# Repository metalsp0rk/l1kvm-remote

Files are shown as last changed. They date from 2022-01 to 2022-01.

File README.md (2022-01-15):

# Level1Techs KVM Remote

USB Remote for the Level1Techs KVM using Raspberry Pi Pico

# Hardware

## Bill of Materials

| Count | Device | Notes | Link |
| ----  | ----- | ----- | ---- |
| 1 | Raspberry Pi Pico | | https://www.adafruit.com/product/4864 |
| 5 | 12mm Round Tactile Switch | These switches come with button caps.  If you don't like the colors, I've included a 3mf file so you can print your own. | https://www.adafruit.com/product/1009 |
| 2 | M3x20mm button head cap screw | | (https://www.mcmaster.com/92095A185/  |

## Enclosure

The enclosure is a 3 piece design, with optional mounting ears for screwing the remote onto a mounting surface.  The front component is designed so that the buttons are flush with the front of the enclosure.  The button mount is designed to hold the tactile switches with ~0.5mm of tolerance.  The pins should be exposed by ~1-2mm on the bottom of the mount, for ease of soldering when assembled.  The rear casing holds the Pi Pico and has ample room to hold wiring.  The Pico is located on the mount with conical pins and held in place with hot glue.  

Suggestions for improvements on the models are always welcome.

## Building

### Which parts to print

To build a complete unit, you'll need one of each of the following parts:

 - [Front Fascia](3MF/1-front_fascia.3mf)
 - One of: [Button Mount](3MF/2-button_mount.3mf) or [Button Mount with ears](3MF/2-button_mount_ears.3mf)
 - [Rear Casing](3MF/3-rear_casing.3mf)

If you want to mount the enclosure with screws, choose the button mount with ears.

The rear casing requires support or a printer that is _extremely good_ at bridging, so enable support.

Optionally, you can also print buttons for the switches.  You'll need 5 copies of [Switch Button](3MF/4-switch_button.3mf).

Switch buttons should be printed at a layer height of 0.12-0.16mm if possible, and all other components can be printed between 0.16-0.2mm layer height.  If you want, you can print all components on the same print, at a 0.16mm layer height.  This 8 piece print took approximately 10 hours on my Ender 3, so set the print and go out for a night on the town.

# Keymappings

We've got 5 buttons; 4 for directly changing inputs, one to act as a "modifier"

Here's the mapping table:
|  BTN  |  BASE  |  MOD |
| ----- | --- | --- |
| 1 |  MOD | NONE |
| 2 | HEAD 1 | AUDIO FOLLOW |
| 3 | HEAD 2 | AUDIO LOCK |
| 4 | HEAD 3 | USB FOLLOW |
| 5 | HEAD 4 | USB LOCK |

# Software

## Dependencies

Ubuntu:

```
sudo apt install cmake gcc-arm-none-eabi libnewlib-arm-none-eabi libstdc++-arm-none-eabi-newlib
```

### PicoProbe and PicoTool

If you want to use OpenOCD and a PicoProbe for development, you'll need to use the Raspberry Pi Foundation fork of OpenOCD until they upstream their changes.  This can be found at:

https://github.com/raspberrypi/openocd

Once you've installed OpenOCD, you'll need to build and flash a picoprobe:

https://github.com/raspberrypi/picoprobe

A more detailed guide can be found here: 

https://www.digikey.com/en/maker/projects/raspberry-pi-pico-and-rp2040-cc-part-2-debugging-with-vs-code/470abc7efb07432b82c95f6f67f184c0

## Building

```
mkdir build
cd build
cmake -DCMAKE_BUILD_TYPE=Release ..
make
```

## Debugging

Include Debug symbols.
```
cmake -DCMAKE_BUILD_TYPE=Debug ..
```
I've included a GDB sample for my macros, if you want to use GDB, go for it, otherwise, vscode has a good debugger, you just need to set up OpenOCD as your debugging target.

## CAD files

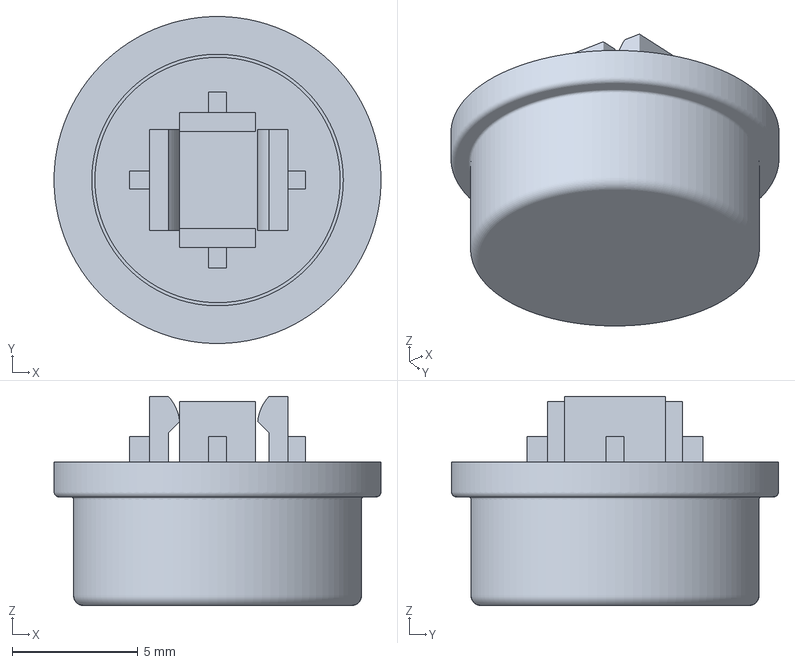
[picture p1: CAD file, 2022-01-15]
3MF/4-switch_button.3mf
13.0 x 13.0 x 8.32 mm

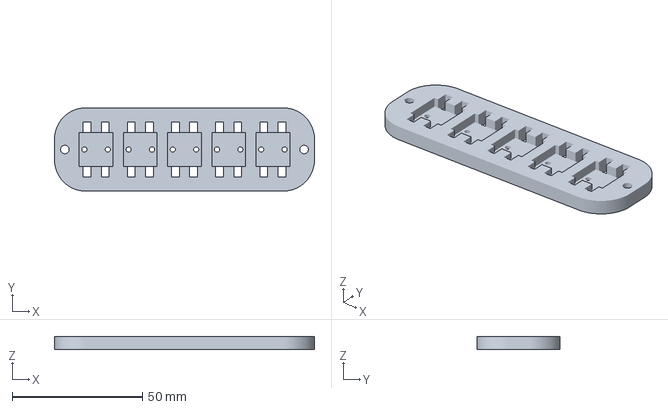
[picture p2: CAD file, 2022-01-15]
3MF/2-button_mount.3mf
100.0 x 32.0 x 5.00 mm

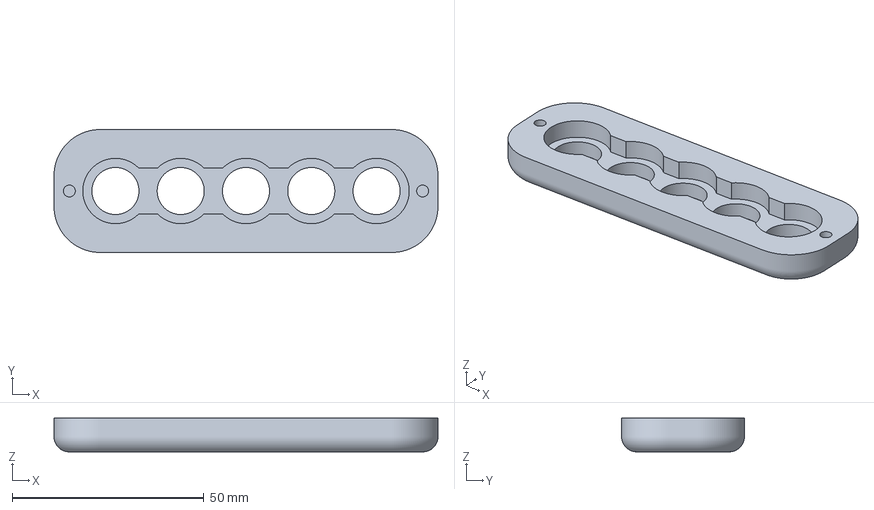
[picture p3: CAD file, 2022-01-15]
3MF/1-front_fascia.3mf
100.0 x 32.0 x 8.80 mm

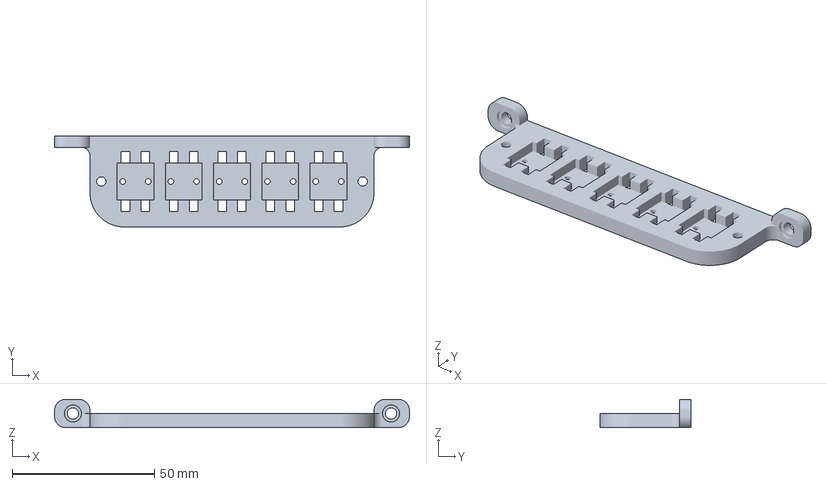
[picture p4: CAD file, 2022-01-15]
3MF/2-button_mount_ears.3mf
125.0 x 32.0 x 10.0 mm

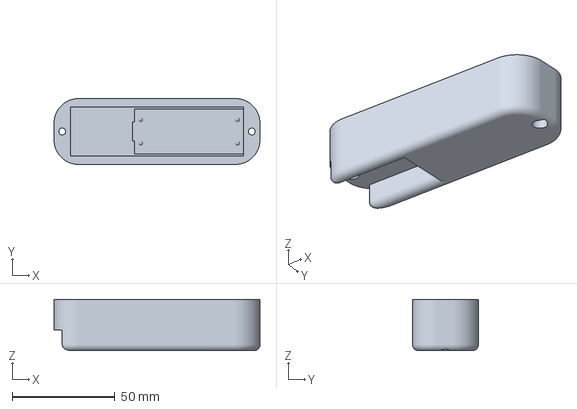
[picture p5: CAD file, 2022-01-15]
3MF/3-rear_casing.3mf
100.0 x 32.0 x 25.0 mm

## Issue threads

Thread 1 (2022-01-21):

Bottom casing does not have access hole for pi pico button

metalsp0rk, 2022-01-21:
If we ever need to flash new firmware to the Pi Pico, we'll have to disassemble the unit and remove the Pico from the housing.  While this is technically non-destructive, with the exception of hot glue, it is tedious and a better solution would be to include an access hole that would allow a paper clip to actuate the firmware flash button from the outside casing.

metalsp0rk, 2024-05-10:
New prototype rear housing is complete in CAD, planning on working out #2 before uploading new models.

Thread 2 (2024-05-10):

Improve mounting bracket

metalsp0rk, 2024-05-10:
The mounting bracket is ugly.  Let's come up with a better solution for this.

maybe through-holes are good for this, but where do we put them?  There's no space for them in the housing.  What if we put the ears on the rear housing instead?

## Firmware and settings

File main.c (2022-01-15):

#include <stdlib.h>
#include <stdio.h>
#include <string.h>

#include "pico/util/queue.h"
#include "pico/stdlib.h"
#include "bsp/board.h"
#include "tusb.h"
#include "usb_descriptors.h"


// Where we begin our GPIO pins.
#define GPIO_OFFSET 2

/* Blink pattern
 * - 250 ms  : device not mounted
 * - 1000 ms : device mounted
 * - 2500 ms : device is suspended
 */
enum  {
  BLINK_NOT_MOUNTED = 250,
  BLINK_MOUNTED = 1000,
  BLINK_SUSPENDED = 2500,
};

static uint32_t blink_interval_ms = BLINK_NOT_MOUNTED;

queue_t keysend_queue;

typedef struct {
  uint8_t keycode[6];
} keysend_task_t;

void led_blinking_task(void);
void hid_task(void);
void keysend_task(void);

/*------------- MAIN -------------*/
int main(void)
{
  board_init();
  tusb_init();

  queue_init(&keysend_queue, sizeof(keysend_task_t), 8);

  for (uint8_t i=0; i < 5; i++) {
    gpio_init(i+GPIO_OFFSET);
    gpio_set_dir(i+GPIO_OFFSET, GPIO_OUT);
    printf("Initializing GPIO %d\n", i+GPIO_OFFSET);
  }

  while (1)
  {
    tud_task(); // tinyusb device task
    led_blinking_task();

    hid_task();
    keysend_task();
  }

  return 0;
}

//--------------------------------------------------------------------+
// Device callbacks
//--------------------------------------------------------------------+

// Invoked when device is mounted
void tud_mount_cb(void)
{
  blink_interval_ms = BLINK_MOUNTED;
}

// Invoked when device is unmounted
void tud_umount_cb(void)
{
  blink_interval_ms = BLINK_NOT_MOUNTED;
}

// Invoked when usb bus is suspended
// remote_wakeup_en : if host allow us  to perform remote wakeup
// Within 7ms, device must draw an average of current less than 2.5 mA from bus
void tud_suspend_cb(bool remote_wakeup_en)
{
  (void) remote_wakeup_en;
  blink_interval_ms = BLINK_SUSPENDED;
}

// Invoked when usb bus is resumed
void tud_resume_cb(void)
{
  blink_interval_ms = BLINK_MOUNTED;
}

//--------------------------------------------------------------------+
// USB HID
//--------------------------------------------------------------------+

bool btnstate[5] = { false };
bool prevbtnstate[5] = { false };

void hid_task(void)
{
  // Poll every 10ms
  const uint32_t interval_ms = 30;
  static uint32_t start_ms = 0;

  if ( board_millis() - start_ms < interval_ms) return; // not enough time
  start_ms += interval_ms;

  bool btn = false;

  for (uint8_t i=0; i < 5; i++) {
    btnstate[i] = gpio_get(i+GPIO_OFFSET);
    if (btnstate[i]) btn = true;
    /*if (btn) printf("Got Button State\n");*/
  }
    if (btnstate[0]) {
      printf("BTN 0 MOD Down\n");

      // Audio Follows
      if(btnstate[1] && !prevbtnstate[1]){
        keysend_task_t keycode_item = { .keycode = { 0 } };
        keycode_item.keycode[0] = HID_KEY_SCROLL_LOCK;
        queue_try_add(&keysend_queue, &keycode_item);
        queue_try_add(&keysend_queue, &keycode_item);
        keycode_item.keycode[0] = HID_KEY_F5;
        queue_try_add(&keysend_queue, &keycode_item);
      }
      // Audio Current
      if(btnstate[2] && !prevbtnstate[2]){
        keysend_task_t keycode_item = { .keycode = { 0 } };
        keycode_item.keycode[0] = HID_KEY_SCROLL_LOCK;
        queue_try_add(&keysend_queue, &keycode_item);
        queue_try_add(&keysend_queue, &keycode_item);
        keycode_item.keycode[0] = HID_KEY_A;
        queue_try_add(&keysend_queue, &keycode_item);
      }
      // USB Follows
      if(btnstate[3] && !prevbtnstate[3]){
        keysend_task_t keycode_item = { .keycode = { 0 } };
        keycode_item.keycode[0] = HID_KEY_SCROLL_LOCK;
        queue_try_add(&keysend_queue, &keycode_item);
        queue_try_add(&keysend_queue, &keycode_item);
        keycode_item.keycode[0] = HID_KEY_F7;
        queue_try_add(&keysend_queue, &keycode_item);
      }
      // USB Current
      if(btnstate[4] && !prevbtnstate[4]){
        keysend_task_t keycode_item = { .keycode = { 0 } };
        keycode_item.keycode[0] = HID_KEY_SCROLL_LOCK;
        queue_try_add(&keysend_queue, &keycode_item);
        queue_try_add(&keysend_queue, &keycode_item);
        keycode_item.keycode[0] = HID_KEY_U;
        queue_try_add(&keysend_queue, &keycode_item);
      }
    } else {
      // normal switching.
      // Switch to head 1
      if(btnstate[1] && !prevbtnstate[1]){
        keysend_task_t keycode_item = { .keycode = { 0 } };
        keycode_item.keycode[0] = HID_KEY_SCROLL_LOCK;
        queue_try_add(&keysend_queue, &keycode_item);
        queue_try_add(&keysend_queue, &keycode_item);
        keycode_item.keycode[0] = HID_KEY_1;
        queue_try_add(&keysend_queue, &keycode_item);
      }
      // Switch to head 2
      if(btnstate[2] && !prevbtnstate[2]){
        keysend_task_t keycode_item = { .keycode = { 0 } };
        keycode_item.keycode[0] = HID_KEY_SCROLL_LOCK;
        queue_try_add(&keysend_queue, &keycode_item);
        queue_try_add(&keysend_queue, &keycode_item);
        keycode_item.keycode[0] = HID_KEY_2;
        queue_try_add(&keysend_queue, &keycode_item);
      }
      // Switch to head 3
      if(btnstate[3] && !prevbtnstate[3]){
        keysend_task_t keycode_item = { .keycode = { 0 } };
        keycode_item.keycode[0] = HID_KEY_SCROLL_LOCK;
        queue_try_add(&keysend_queue, &keycode_item);
        queue_try_add(&keysend_queue, &keycode_item);
        keycode_item.keycode[0] = HID_KEY_3;
        queue_try_add(&keysend_queue, &keycode_item);
      }
      // Switch to head 4
      if(btnstate[4] && !prevbtnstate[4]){
        keysend_task_t keycode_item = { .keycode = { 0 } };
        keycode_item.keycode[0] = HID_KEY_SCROLL_LOCK;
        queue_try_add(&keysend_queue, &keycode_item);
        queue_try_add(&keysend_queue, &keycode_item);
        keycode_item.keycode[0] = HID_KEY_4;
        queue_try_add(&keysend_queue, &keycode_item);
      }
    }
  for (int i=0;i<5; i++){
    prevbtnstate[i] = btnstate[i];
  }
}

static bool has_keyboard_key = false;
const uint32_t send_interval_ms = 50;
static uint32_t send_start_ms = 0;

void keysend_task(void) {

  if ( board_millis() - send_start_ms < send_interval_ms) return; // not enough time
  send_start_ms += send_interval_ms;
  
  if ( tud_hid_n_ready(ITF_NUM_KEYBOARD) ) {
    // if the key is down, our next interval will be a keyup send.
    if (has_keyboard_key) {
      tud_hid_n_keyboard_report(ITF_NUM_KEYBOARD, 0, 0, NULL);
      has_keyboard_key = false;
    } else {

      keysend_task_t keycode;
      if (!queue_try_remove(&keysend_queue, &keycode)) return;
      tud_hid_n_keyboard_report(ITF_NUM_KEYBOARD, 0, 0, keycode.keycode);
      has_keyboard_key = true;
    }
  }
}

// Invoked when received SET_PROTOCOL request
// protocol is either HID_PROTOCOL_BOOT (0) or HID_PROTOCOL_REPORT (1)
void tud_hid_set_protocol_cb(uint8_t instance, uint8_t protocol)
{
  (void) instance;
  (void) protocol;

  // nothing to do since we use the same compatible boot report for both Boot and Report mode.
  // TOOD set a indicator for user
}

// Invoked when sent REPORT successfully to host
// Application can use this to send the next report
// Note: For composite reports, report[0] is report ID
void tud_hid_report_complete_cb(uint8_t instance, uint8_t const* report, uint8_t len)
{
  (void) instance;
  (void) report;
  (void) len;

  // nothing to do
}

// Invoked when received GET_REPORT control request
// Application must fill buffer report's content and return its length.
// Return zero will cause the stack to STALL request
uint16_t tud_hid_get_report_cb(uint8_t instance, uint8_t report_id, hid_report_type_t report_type, uint8_t* buffer, uint16_t reqlen)
{
  // TODO not Implemented
  (void) instance;
  (void) report_id;
  (void) report_type;
  (void) buffer;
  (void) reqlen;

  return 0;
}

// Invoked when received SET_REPORT control request or
// received data on OUT endpoint ( Report ID = 0, Type = 0 )
void tud_hid_set_report_cb(uint8_t instance, uint8_t report_id, hid_report_type_t report_type, uint8_t const* buffer, uint16_t bufsize)
{
  (void) report_id;

  // keyboard interface
  if (instance == ITF_NUM_KEYBOARD)
  {
    // Set keyboard LED e.g Capslock, Numlock etc...
    if (report_type == HID_REPORT_TYPE_OUTPUT)
    {
      // bufsize should be (at least) 1
      if ( bufsize < 1 ) return;

      uint8_t const kbd_leds = buffer[0];

      if (kbd_leds & KEYBOARD_LED_CAPSLOCK)
      {
        // Capslock On: disable blink, turn led on
        blink_interval_ms = 0;
        board_led_write(true);
      }else
      {
        // Caplocks Off: back to normal blink
        board_led_write(false);
        blink_interval_ms = BLINK_MOUNTED;
      }
    }
  }
}

//--------------------------------------------------------------------+
// BLINKING TASK
//--------------------------------------------------------------------+
// Used for a status message.  
// Final version might be using a LED that's off the board, so we can mount it in the case.
void led_blinking_task(void)
{
  static uint32_t start_ms = 0;
  static bool led_state = false;

  // blink is disabled
  if (!blink_interval_ms) return;

  // Blink every interval ms
  if ( board_millis() - start_ms < blink_interval_ms) return; // not enough time
  start_ms += blink_interval_ms;

  board_led_write(led_state);
  led_state = 1 - led_state; // toggle
}

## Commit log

2022-01-15 initial CAD
    [button_mount.3mf, button_mount_ears.3mf, front_fascia.3mf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]
2022-01-15 rename 3mfs
    [1-front_fascia.3mf, 2-button_mount.3mf, 2-button_mount_ears.3mf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]
2022-01-15 add switch button
    [4-switch_button.3mf]
